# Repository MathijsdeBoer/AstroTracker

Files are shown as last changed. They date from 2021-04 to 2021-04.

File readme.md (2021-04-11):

# Astrotracker

This repository contains the project files for the Astrotracker project.
We're aiming to design a reasonably simple device that allows users to take good shots of the stars at night, without any motion blurring.

## License

As this project involves multiple forms of content, we need to define licenses for each of them separately.
Most well known licenses for code do not cover creative content, nor do they cover CAD.
We try to keep the chosen licenses quite open, to promote sharing and collaborative development.

### Documentation / Development Log

The content in the `doc` directory is licensed under the CC4.0-by-sa-nc license.
This directory is mostly used as a general overview of the concepts explored during the development of the project, and the solutions we find for the inevitable problems along the way.
We'd like to keep that information freely accessible with the chosen license.
Any images that are credited with someone elses name should not be considered to be under this license unless explicitly stated.

### CAD

Any CAD files are licensed under the CERN OHL-W v2.0 or later license.
The way we understand it, this means that if you decided to use (parts of) the designs in your own project, these elements have to be shared with the same license.
For example: we design a doohickey that fenagles the whotsit.
If you incorporate our doohickey design, but don't include our whotsit, you only have to make the design files for the doohickey available.
If you also make changes to the doohickey design files, you must give information about what you changed, and when you changed it, and make them available under the same CERN OHL-W v2.0 or later license.
The recommended approach to sharing the changes is to include these in a `changes.txt` file.
Note that this license only applies to the design _files_, and not a physical object based on them.
The physical object it yours to use, sell, paint, throw in the ocean (please don't), and anything else you can think of.

### Code

Firmware, or other code is licensed under the MIT license.
While this license does not force you to share your changes, we'd like to see your improvements!

Should any part of the text above conflict with any part of the licenses described, the license itself should be considered the correct interpretation.

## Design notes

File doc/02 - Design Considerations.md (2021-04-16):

# Design considerations

The design of the star tracker needs to fulfill a number of prerequesites.
Mainly, it needs to be portable, accurate and in our case, reasonably simple to build.
As we expect that the main manufacturing method of our users is the use of 3D printers, we need to make sure that our designs do not incorporate too many fine details, or too much non-standard hardware if we need to incorporate nuts and bolt, for example.

Additionally, electronic components ought to be easily attainable.
While we'd like to design our own PCBs for our needs, it's probably more likely that Aruino or Raspberry Pi based systems are preferred due to their ubiquity, good support and widely available documentation.
Fancy solutions are nice, but simple solutions are better.
Nevertheless, if we can properly define our PCB specifications and requiremetns we can also design multiple implementations of the board based around a variety of microcontrollers.

## Existing products

If we consider existing star trackers, they share several similarities:

- They can be powered with batteries and with an external power source
- They are mountable on a tripod
- They allow the user to select several speeds
- Mounted cameras are easily aimed at the desired target
- Polar allignment methods are built into the device, or are easily attached
- Some have a go-to function at the cost of size

Taking these features into account, we'd like to distill them down into a so-called Minimum Viable Product (MVP).
This is generally regarded as the minimum amount of working features required to release.
For a star tracker, this is somewhat simple.
We want to turn a mounted camera such that it counteracts the rotation of the earth.
If we can achieve that, we can call it ready for release.

As this is an open source project, "release", of course, means "functional"

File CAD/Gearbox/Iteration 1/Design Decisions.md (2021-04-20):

# 10k : 1 Planetary Gearbox

## Iteration 1

## Design Decisions

This is an initial design for the gearbox that should bring down our stepper motor's rotation to our targeted 10k : 1 reduction.
It was designed with 3D printing in mind, and as such already has some tolerances built in.
The reduction stages are selected as defined in our writeup:

    4 * 4 * 5 * 5 * 5 * 5 = 10,000

Where the `: 1` is left out for clarity.

A module of 2.0 mm for the gears was chosen as a good compromise between size and gear strength.
As we should expect users to attach some expensive equipment to the end, we should probably err on the side of caution, lest the $5000 camera drops on the floor after the teeth shear off.

The current implementation does not, however, use the helical or herringbone (double helical) cut.
Firstly, the used tool to generate the gears has a bug where the module changes as the helical angle increases, which made designing for size more difficult.
Secondly, as the application is not a high-RPM one, the helical cut may not be required after all.

Gear thickness was left at the default 10mm.
Some room for optimization may be found here, though care should be taken to not remove too much as to not reduce gear strength too much.

In terms of planetary gear setups, we've opted to fit as many as physically would fit per stage.
This works out to 5 planetary gears for the 4 : 1 stages, and 4 for the 5 : 1 stages.
This could be reduced to 3
However, we've again erred on the side of caution and opted to distribute any forces through as many gears as we could fit.

The carriers and planetary gears were designed to be fitted with 608 sized ball bearings.
This size of bearing is relatively ubiquitous and should be comparatively cheap.
These should keep things moving quite smoothly, though no tests on designs without bearings have been performed.
Removal of these bearings in favour of a simpler rod and hole setup might also allow us to reduce the thickness of the carriers, reducing overal size.

Finally, we added a little galaxy design to the gears, because it looks neat while reducing a little bit of material.

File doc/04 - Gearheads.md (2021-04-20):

# Gearheads

As we discussed, existing hobby grade motors probably won't be able to rotate at the desired 0.000696 RPM.
We'll need to design a gearbox that can take a higher RPM from the motor, and bring it down to the lower RPM.
Now, gearboxes are a whole can of worms we're going to open.

## The gear

_The Gear._
This little invention that you can [track back thousands of years](https://en.wikipedia.org/wiki/Gear#History) and is still in use today.
From gearboxes in cars to mechanical clocks to cameras and more!
The idea of a gear is that it interlocks with a similar object, and through it's rotation imparts a movement.
Gear ratios, the ratio of the amount of teeth between two or more gears, have the added benefit that they can increase or decrease the amount of torque, at the benefit or cost of rotational speed respectively.

<div style="text-align:center">
Animation of gears
<p>Gears rotating. The smaller gear has a larger rotational velocity to keep up with the larger gear, Simiprof, 2013.</p>
</div>

Now, these things have been around for so long, that humans have tried a lot of things with them, and their design.
Equally ubiquitous are terms for describing very specific parts of the gear.
We won't be going into detail on these.
But we'll have warned you, lest we make a mechanical engineer very sad.

<div style="text-align:center">
Gear terminology
<p>Terminology used to describe the anatomy of a gear, Honaroog, 2007.</p>
</div>

Another value to keep in mind is the [module](https://en.wikipedia.org/wiki/Gear#Standard_pitches_and_the_module_system) of the gear.
This value describes the relationship between the amount of teeth and the pitch diameter (pitch circle on the image).
The lower the module, the smaller the gear and its teeth.

So what about these ratios?
This is pretty simple, really.
If you take the amount of teeth of one gear, and divide it by the amount of teeth on the other gear, you get the gear ratio.
For example: gear A has 10 teeth, and we interface it with gear B with 100 teeth.
In order for gear A to completely rotate gear B, it needs to rotate 10 times to "visit" the 100 teeth of gear B.
Ergo, the gear ratio here is 10 : 1.
10 rotations cause 1 rotation.
The reverse is also true, if we take gear B as our input gear now, every rotation of gear B causes 10 rotations of gear A.
This gear ratio is 1 : 10.
Some people like to use decimal numbers to indicate their ratios, such as 0.1 : 1.
Mainly for less evenly dividable values, such as 23 : 31 to 1 : 1.347.
This is purely a matter of preference, but the end results are the same.

### I like the cut of your ~~jib~~ Gear

Gears can come in a few shapes and sizes, as we've discussed, but they can also come in different cuts.
A cut determines how the teeth are shaped around the axis of rotation.
The most well know cuts are the [straight cuts](https://en.wikipedia.org/wiki/Gear#Spur) (also known as spur gear).
These are what you would picture if you think "gear".
The other popular cut would be the [helical gear](https://en.wikipedia.org/wiki/Gear#Helical).
These have their gears twist around the rotational axis in a, well, helix.
A variation on the helical gear is the double helical, these will switch the direction of their twist halfway along the gear's width.

The main benefit of a straight cut is the larger contact area between two gears.
This allows for a larger change in force application.
Unfortunately, they tend to be somewhat noisy at high speeds.
Their efficiency and simple construction makes them preferable in racing gear boxes, for example.

Helical gears are smoother than the straight cut gears, because they grow and shrink their contact surface gradually as the teeth interact.
You'll find these a lot in you car's gearbox, or other applications where high RPM and low noise are desired.
Downside of them is that they impart a force along the rotational axis, reducing the efficiency, and requiring some measures to counter this thrust.

The double helical gear aims to negate the axial load by doubling up on the helical direction, one half goes one way, the other one goes the other.
These have the benefit of the smooth contact patch provided by the helical gear while generating a net zero lateral force.
This makes them interchangeable with straight cut gears, but substantially more complex to manufacture.

<div style="text-align:center">
Gear Cuts
<p>Differently cut gears. Green is the straight cut, purple is the helical cut and orange is the double helical cut, BavariaSHAPE, 2020</p>
</div>

As we're not dealing with a high RPM application, the exact type of gear should not matter too much.
Helical gears are nice, though, for their increased smoothness.
Double helical gears do the same, but they also look cool.
And why build anything functional while not making it look cool?

There are many, many more gear configurations, but they are not as immediately relevant to our project.

## Metal boxes

Taking a few of these gears, and putting them in a neat little box, is commonly referred to as a gearbox.
Shocker, we know.
But these little (or large) things have been very useful to us.
Gearboxes are used to combine gear ratios into a more useful ratio without having to create very large or very small gears by doing the reductions or increases in several steps.

### Spur gearbox

Spur gearboxes are the simplest combination of gears.
The input gear drives the next, which drives the next, and so on untill you reach the output gear.
Now, the name of this one may imply only straight cut gears are used, but that is not nessecarily true.
It's mainly just the name we could find for it in our internet searches, and we all know that if it's online, it must be true.

They are by far the simplest to design, build and maintain and are as such widely used.
Unfortunately, they also wear a little faster than the planetary gearset, which we'll expand on later.
This is mainly due to the fact that each gear puts full load on the next, which causes stress on the parts and reduces their lifespan.

### Planetary gearset

While stargears are, to the best of our knowledge, not a real thing, sun gears and planetary gears are.
These are found in, get this, planetary gearboxes.
I wonder where they got this term from?
I guess we'll never know.

<div style="text-align:center">
Planetary Gearset
<p>A planetary gearset. Red is the ring gear, blue are the planetary gears, yellow is the sun gear and green is the carrier, Wapcaplet, 2006</p>
</div>

The planetary gearset has a few configurations.
Generally an input and output is defined, and the remaining element is held stationary.
The carrier and planetary gears should be considered part of the same element.
For example: you can take the sun gear as input, and the carrier as output, this would mean that you would need to hold the ring gear stationary
If you want to use the ring gear as output instead, you would have to keep the carrier stationary.

This versatility allows the planetary gearset to be used in various ways at the cost of complexity.
With the spur gearbox, a 10 : 1 reduction requires only 2 gears.
The planetary gearset requires at _least_ 4, preferably 5.
One sun gear, 2 or 3 planetary gears and a ring gear, not to mention the carrier.
If you have to chain several of these reductions, the amount of moving parts increases by a lot.
Additionally, the gears need to be fairly precise, if one planetary gear is slightly out of allignment, it will cause premature wear and failures.
At the cost of this complexity, you gain a lot of reliability and achieve a comparatively smaller footprint for the same reduction.

<div style="text-align:center">
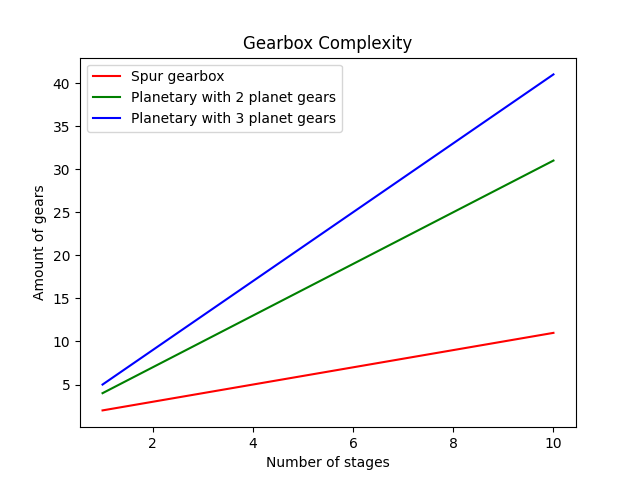
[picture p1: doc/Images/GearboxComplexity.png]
Gearbox complexity increasing with each stage

<p>The amount of gears per stage of reduction for the described gearbox types.</p>
</div>

### Other options

We would be amiss if we were not to mention the worm gear.
Beloved by engineers and birds alike, this gear uses a screw-shaped gear, the worm gear, and interfaces it with a regular gear, the worm wheel.
Because, generally, a worm gear is one long tooth, you can get a very large reduction in a relatively small package.
For example, if we combine our worm gear with a 100 tooth worm wheel, we get a 100 : 1 reduction.

This is not without issues, though.
The worm gear cannot be back-driven, which means that you can't rotate the output to rotate the input, and the output rotational axis is at an angle from the input, which may make designing a gearbox difficult.
On top of this, the efficiency of a worm gear is not as high as other setups due to the increased friction.

Finally, we have the harmonic drive, which uses a flexible inner gear in a solid outer gear.
The flexing gear has a few less teeth than the outer gear, and is flexed into contact by an internal oval shape.
These have also allowed for impressive gear ratios in small packages.
Unfortunately, these are also quite difficult to get right for hobbyists.

## What does this mean for us?

It's hard to say if using a spur gearbox or a planetary gearset is the best for our purpose.
With our relatively low torque and RPM application, neither's strengths and weaknesses really have an impact.
However, as someone will probably mount their expensive camera to the other end, we'll most likely want the improved reliability of the planetary gearsets.
The increased complexity will have to be a hit we'll take.

As we're targeting a 10,000 : 1 total reduction, we have a few options to divide this up:

    10 : 1
    ^ We're using that number in this section, the  ": 1" is implied

    4 * 4 * 5 * 5 * 5 * 5   = 10,000
    10 * 10 * 10 * 10       = 10,000
    100 * 100               = 10,000

There are more possible combinations, of course, but there is a balance to be struck between the amount of stages and keeping the individual reductions relatively small.
As the reduction grows, so does the amount of teeth involved, increasing the size of the gears.
Conversely, as the individual reductions are smaller, more stages are needed to get to the same result.
As we don't want to create gears that are too small or too large, we need to set a minimum and maximum amount of teeth we are willing to use.
We aim to stay above 10, and below 60, though you might find your manufacturing capabilities allowing for values outside this range.
As we use a 3D printer, we shouldn't use a module of lower than 1.0mm, which is about as small as you would reasonably want to go on an FDM printer with a 0.4mm nozzle.

To determine the numbers of teeth we need for our sun gears, planet gears and ring gear, we use [this online tool](http://www.thecatalystis.com/gears/).
With some careful mathematical operations (read: we guessed and tried random numbers) we aimed to generate the reductions described above, and checked them against our desired amount of teeth.
The smallest we could reasonably get a 10 : 1 reduction used too many teeth in the ring gear, and we could not even get a 100 : 1 reduction in the tool.
4 : 1 and 5 : 1 is very achievable, though, and we even found a solution that uses the same amount of teeth in the ring gear, which would let us use the same ring gear for all of our reductions in one neat package!
The found values ended up being:

    4 : 1 Reduction:
        Sun Gear: 16 teeth
        Planet Gear: 16 teeth
        Ring Gear: 48 teeth
    5 : 1
        Sun Gear: 12 teeth
        Planet Gear: 18 teeth
        Ring Gear: 48 teeth

In theory, we could go even smaller with 24 teeth on the ring gear, however, the sun gear would be 8 teeth for the 4 : 1 reduction, and 6 for the 5 : reduction.
Both these fall outside the range we're willing to use, as larger gears allow for a little more load.

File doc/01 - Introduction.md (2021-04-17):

# Introduction

The Stars!

The stars?

Yes! The stars! And those other stellar objects, too, I guess.

What about them?

Have you never wanted to take a photo of them?

Well sure, but my (phone) camera is not good enough to get nice results I can share on my [insert social media] page.
Even the moon can be tricky!

A-ha!
But it does not have to be that hard, you just need to know how to use your equipment to get the results you want!

But how?

Don't worry, people have been taking stellar pictures with cheap hardware for _years_, if they can get their amazing results, your modern smartphone can do it for sure.

## Stellar photography

Depicting the stars is an art as [old as time](https://en.wikipedia.org/wiki/History_of_astronomy).
It should therefore not be surprising that, not long after it was invented, this was also extended to photography.
While the initial [Daguerrotype](https://en.wikipedia.org/wiki/Daguerreotype) style photographs were only usable for bright objects, it wasn't too long after that new developments in photography allowed for more sensitivity to the dimmer objects.
For reference, the first successful Daguerrotype image of the sun's corona in 1851 took an 84 seconds exposure!

<div style="text-align:center">
Daguerrotype of the sun, Johann Julius Friedrich Berkowski, 1851
<p>Johann Julius Friedrich Berkowski, 1851</p>
</div>

It wasn't untill the widespread availability of [dry plate photography](https://en.wikipedia.org/wiki/Dry_plate) that astrophotography became a more manageable process.
Henry Draper, for example, used a 51 minute exposure in 1880 to be the first person to capture the Orion Nebula.
Where his colleague, Andrew Ainslie Common, built his own telescope in his shed and used several hour-long exposures of the same nebula to show stars that the human eye can not see three years later.
A similar process is still used today, known as "stacking".

<div style="text-align:center">
Orion Nebula, Henry Draper, 1880
<p>Henry Draper, 1880</p>
</div>

<div style="text-align:center">
Orion Nebula, Andrew Ainslie Common, 1883
The telescope used by Andrew Ainslie Common, built into his shed, built in 1876, unknown date
<p>Left: Andrew Ainslie Common, 1883, right: The telescope built by him</p>
</div>

If people that built their own telescopes in their backyards, with the technology of the day that fights against them in almost any conceivable way, can take the types of pictures shown above, we sure as hell can do it with the seas of information that can be found on the internet! Right?

Source(s): Wikipedia

## Collecting light

As you may have picked up on, or already knew, taking photos of things requires one element you don't have a lot of at night: light!
Generally speaking, short of going to a brighter area a camera has three things it can do to increase the amount of light that gets to the sensor; increase the diameter of the lens aperture, take a longer exposure, increase the ISO.
The aperture can only open so far, and is generally not enough to make up for the low light alone.
The ISO, simply said, is the camera multiplying the amount of measured light with some value.
Unfortunately, in systems with a low amount of measured data, noise has a strong effect on the end result.
Finally, if you increase the exposure time, you collect light over a longer amount of time, easy!
But hold on!
Doing this also increases the effect of motion blur, which isn't something you want for nice and crispy shots!

All these settings, and they all have their drawbacks!

## So what do _I_ need?

A camera.

Joking aside, you don't really need a good camera, but it's nice if you do.
Amateur astrophotographers have been using old webcams for about as long as they have been available.
More recently, Raspberry Pis have had some level of use, too.
That is not to say that a phone does not work.
At the other end of the scales you have your DSLR/Mirrorless cameras, and dedicated astrocameras.
These may be out of the price range of many people though.
It's worth mentioning that entry level DSLRs tend to be in the $300 bracket, and are usable for things other than pretty star pictures.

The main issue that most budding astrophotographers face is that they simply don't have a stable enough platform to take their pictures with.
While you can freehand a DSLR to take photos of the moon, getting Andromeda may not be as simple.
A good tripod or other stable mount may be needed.
Because these other objects are so dim, you need to increase the amount of time your camera takes to take a picture.
That, or you find a lens with a insanely large aperture, probably at an equally insane price.

But my pictures are still blurry!

Yes, well, while the camera may be perfectly still, the earth isn't.
You may have missed it, but once every 24 hours or so, we do a full rotation!
This has the effect of the illusion that the sky is moving around us.
Whether we are moving, or the sky is has little bearing on the result: The stars start streaking.

<div style="text-align:center">
Star trails, Akiyoshi's Room
<p>Star trails, Akiyoshi's Room, unknown date</p>
</div>

While this has its artistic merit, it might not be what you want.
There's two main ways to solve this. We can decrease exposure time, reducing the amount of light per photo.
This has the issue that you need to take a lot more photos to gather the same amount of light.
Stacking is used to combine these images after the fact.
Alternatively we find a way to keep the camera pointed at the same point in the sky. Enter: The star tracker!

## Star trackers

Star trackers are neat little devices that counter the rotation of the earth.
Generally attached to a nice and steady tripod, they slowly rotate the camera around to, you guessed it, track the stars' motion.
This way you can get a nice and sharp picture of a moving subject in dark settings.

Commercial products already exist to fulfill this purpose.
Their price varies, but they will generally be in the $400 area, depending on your location.
Why spend that amount of money, when you can spend more on materials, time and failures to build one your own?

## Purpose

This writeup is meant for the reader to use as a reference, explanation or supporting document for our design.
Some of you may have other tools you can use that you might want to incorporate in your production process.
It's not unreasonable that at least a few of you have a lathe, CNC, laser cutter, et cetera.
These tools might provide you with better results than a 3D printer can, but you might have to redesign some part(s).
The writeup would then function as a reference to why we did what we did, for you to interpret and adapt to your own needs.

In this repository, we're exploring the design, and implementation details of a star tracker.
What considerations do we have to make, and how do we go about implementing it?
Answers to these questions will hopefully be answered when we have the time to work on this project.
External contributions are also very welcome, and even encouraged!
As this project touches on many different fields (mechanical, electrical, astronomical, hobbyistical, etc.) there will always be someone who knows more on a particular subject than we do, and we encourage these people to point out and/or correct mistakes we make along the way!

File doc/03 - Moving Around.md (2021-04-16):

# Moving Around

How fast do we need to spin our camera around?
Quite simple, as fast as the earth spins!
But how fast does the earth spin?
About 24 hours.
Is that accurate enough?
Probably not.

## The Rotation of the Earth

As our planet tries to keep the sun at an arm's length (it's got quite the fiery temper), it also twirls around it's rotational axis.
It does this every 86,164.0905 seconds, that is 23 hours, 56 minutes and 4.0905 seconds ([thanks Wikipedia!](https://en.wikipedia.org/wiki/Sidereal_time)).
It's worth mentioning that this is in relation to the stars, where as [solar time](https://en.wikipedia.org/wiki/Solar_time) is what we know as the standard 24 hour day (and even that is somewhat inaccurate as the earth orbits the sun!).
The rotation relative to the stars is known as sidereal time.
This is the time we need to use to calculate our desired RPM.

Let's first convert from seconds to minutes:

    86164.0905 / 60 = 1,436.068175

Now that we have the period, we can convert it to frequency:

    1 / 1,436.068175 = 6.9634577063167631299955519173036e-4 rpm

Eesh, that's a lot of significant figures for a very small value.
How much of these do we actually need?

The mathematically inclined among us are probably already able to estimate the rough numbers, but it's always nice to get confirmation.

Let's do some math.

```python
import matplotlib.pyplot as plt

significant_number = 6.9634577063167631299955519173036e-4
sig_figs = [x for x in range(3, 32)]
error = []

for s in sig_figs:
    rounded = round(significant_number, s)
    # Rounding errors at these scales can cause negative numbers
    err = abs((1.0 - (significant_number / rounded)) * 100.0)
    error.append(err)

plt.scatter(x=sig_figs, y=error)
plt.title("Error vs Significant Figures")
plt.xlabel("Significant Figures")
plt.ylabel("Error (%)")
plt.yscale("log")
plt.ylim(10e-24, 1000.0)
plt.show()
```

<div style="text-align:center">
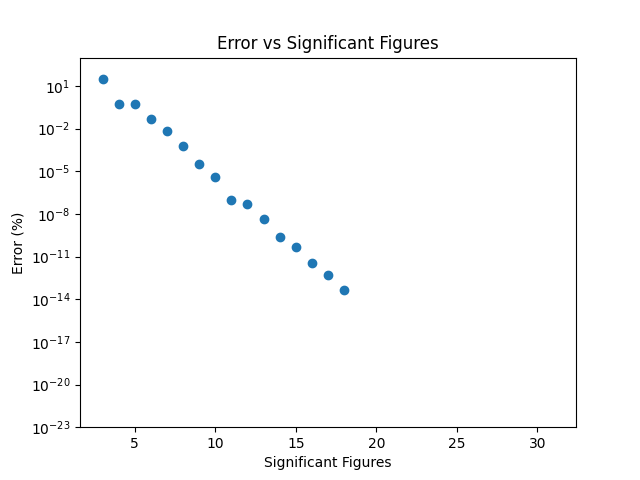
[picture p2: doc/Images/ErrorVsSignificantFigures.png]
Plot of the error vs the amount of significant figures

<p>The error (in %) versus the amount of significant figures, note the plot ending at about 16 figures, this is where Python gave up</p>
</div>

In table form:

| Rounded Value | Error|
| ---: | :--- |
| 0.001 | 30.365422936832363% |
| 0.0007 | 0.5220327669033797% |
| 0.00070 | 0.5220327669033797% |
| 0.000696 | 0.04967968845923654% |
| 0.0006963 | 0.006573406818377592% |
| 0.00069635 | 0.0006073624360780627% |
| 0.000696346 | 3.293884415223047e-05% |
| 0.0006963458 | 4.217491311742094e-06% |
| 0.00069634577 | 9.071303708196865e-08% |
| 0.000696345771 | 5.2893789348473774e-08% |
| 0.0006963457706 | 4.548939003257146e-09% |
| 0.00069634577063 | 2.4071855619922644e-10% |
| 0.000696345770632 | 4.647393581080905e-11% |
| 0.0006963457706317 | 3.397282455352979e-12% |
| 0.00069634577063168 | 5.329070518200751e-13% |
| 0.000696345770631676 | 4.440892098500626e-14% |

Further entries omitted because the values became too small for my Python script to handle.

With this knowledge, we need to set a reasonable error measure.
If we are shooting with an [APS-C](https://en.wikipedia.org/wiki/APS-C) sensor and a 600mm lens, which would probably be the longest lens someone would reasonably want to use (or could afford!).
If we plug this into [Stellarium](https://stellarium.org/en_GB/), a tool that lets you explore the night sky at your location, we arrive at an angular width of a little more than 2 degrees, and an angular height of about 1.5 degrees.
That seems like a respectable goal. Staying under this would mean that you could, in theory track an object over the course of at least a sidereal day without adjusting.

<div style="text-align:center">
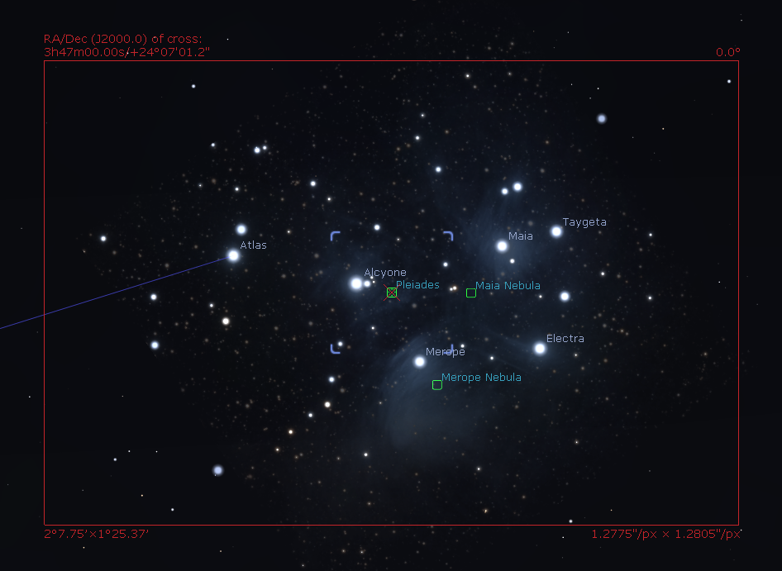
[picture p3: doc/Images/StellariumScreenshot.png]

<p>Screenshot of Stellarium, with the angular dimensions of the image on the bottom left.</p>
</div>

If we can stay under a 1 degree drift per 24 hours, we'll already have a very accurate tracker.
This would work out to about a

`(1 / 360) * 100 = 0.28% error`

Is this attainable?
If we look back at our table, we can see that if we use a value of `6.96e-3` we would already be at an error of 0.05% or

`(x / 360) * 100 = 0.05%`

`x / 360 = 0.0005`

`x = 0.18 degree error`

per 24 hours.

Adding one more significant figure boosts us to a 0.02 degree error, but we should be careful to not fall into the trap of overextending our goals.
Fortunately, changing the amount of significant figures is a firmware detail, and should be relatively easily adapted, depending on our hardware.

## Hardware

Speaking of hardware, we should start looking at what kind of motors we can get.
Mainly, we should select on accuracy.
It would be a shame if we spent all that time calculating our desired output RPM, and it turns out that our motor selection causes it to drift!

### DC motors

The simplest motors you can find are probably the [DC motors](https://en.wikipedia.org/wiki/DC_motor).
They take a free-spinning magnetic core and give it motion by enabling and disabling electromagnets in a certain fashion.
These are often found in RC cars and drones to drive the wheels or propellers.
We'll spare you the exact details how they work, but the gist is, zappy stuff in, spinny stuff out.
The zappier the stuff, the spinnier the out, untill the motor eventually melts.

Now, generally these motors have a certain RPM at a certain voltage.
However, unless you spend a reasonable amount of money on one, the exact RPM is not guaranteed.
As you increase the amount of load (i.e.: More weight) on the motor, the RPM at the same voltage may change.
This is not as large an issue for most applications, and there are ways to accurately control the RPM through some clever circuitry.
However, we feel it's simpler to use a stepper motor instead.

### Stepper motors

[Stepper motors](https://en.wikipedia.org/wiki/Stepper_motor) are also DC motors, with the advantage that it divides a full rotation in equal steps.
Through a certain magnet geometry the output of the shaft can be rotated by a specific amount each time an electromagnet is turned on or off.
Now, the motor does not know _where_ it is pointing, all it knows is where it is going.

<div style="text-align:center">
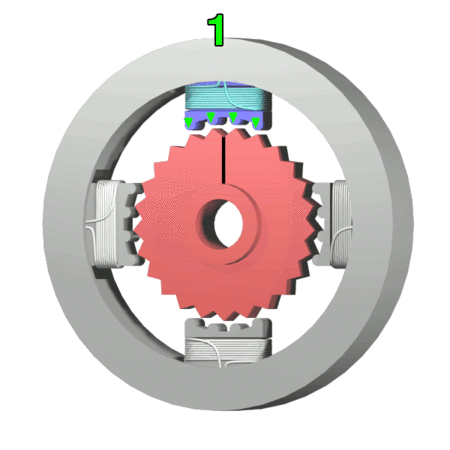
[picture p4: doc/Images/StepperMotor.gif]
Animation showing the function of a Stepper Motor

<p>Animation that shows how a stepper motor works. As each electromagnet is turned on the center magnet moves by a set amount. Wapcaplet/Teravolt, 2010</p>
</div>

This has the advantage that, knowing how many steps each rotation takes, you can be very accurate with your positioning.
The lack of information about your current angle can be mitigated with external solutions, or in some cases, you don't even need to know.
3D Printers make wide use of stepper motors to move their print heads around, to great results.

The downside to stepper motors is that they, well, step.
Ideally we would get a smooth motion to match the stars' movement instead of the slightly jittery movement that is inherent in stepper motors.

### Servo

It would be a miss if we didn't mention [servo motors](https://en.wikipedia.org/wiki/Servomotor).
Servo motors differ from the previous two in that it knows exactly where it is pointing and where it needs to be.
If you tell the motor to point at 90 degrees it will figure out how to get there by taking the difference between it's current position and the target position and using it as an error signal to correct with.
Unfortunately, the drawback is that a servo is only as good as it's position encoder, and cheaper servos don't have very accurate encoders.
Not to say that they are wildly inaccurate for their intended purpose, they just probably won't be accurate enough for our purpose.

### Weapon of choice

All these motors have their own benefits and drawbacks.
Nevertheless, the easiest choice would be the stepper motor.
With the amount of steps being known, we can have a very fine control over the RPM by stepping at a certain rate.
The jitter of the steps should also be reduced if we take a stepper with a sufficiently high amount of steps per revolution.
Additionally, none of the motors (at hobbyist prices) described can reliable rotate at an RPM of 0.000696 rpm.
We'll definately need to use some form of gearbox to reduce the output of the motor, further decreasing the effect of the steps on the photos.

NEMA stepper motors are probably the more well known examples.
These are widely found in various applications because of their standardized design, specified by the [NEMA](https://en.wikipedia.org/wiki/National_Electrical_Manufacturers_Association).
This is not to say that you buy your NEMA stepppers from this association, they just tell manufacturers what the dimensions need to be, where the following number specifies a certain size.
This means that any motor that is sold as a NEMA 8/17/24 by manufacturer A will fit if you initially planned on using the same NEMA motor from manufacturer B without a redesign.
Differences between things such as voltages, holding torques and rated current do exist, so keep that in mind.

<div style="text-align:center">
NEMA 17 motor
<p>NEMA 17 motor, Robotdigg, 2013</p>
</div>

Another well-known little motor is the 28BYJ-48.
This tiny little thing is a staple in a lot of hobby projects due to it's low cost and small size.
Perhaps surprisingly, this motor tends to have more steps per revolution than the average NEMA 17.
It's worth mentioning however, that not all 28BYJ-48 are built to the same specification.
Some have 4096 (!) steps per revolution, some have a few less, some have a lot less.
This is achieved with an internal gearbox that steps down the motor inside, but gear ratios can vary between manufacturers.
When you use one of these, make sure to determine how many steps you have accurately.

<div style="text-align:center">
28BYJ-48 with a stepper driver
<p>28BYJ-48 stepper motor, attached to a ULN2003 stepper driver board, Kushagra Keshari, 2019</p>
</div>

While cheaper NEMA 17 motors are mostly available in 200 steps per revolution (1.8 degree/step), 400 steps per revolution (0.9 degrees/step) motors also exist.
However, these do not stack up against the 4096 steps per revolution (0,0889 degrees/step).
What these motors lack in comparative resolution, they make up in top speed and torque.
We've done some experimenting with the 28BYJ-48, and could not reliably get it to spin faster than about 15 RPM, whereas a NEMA17 will happily do 120RPM with room to spare.
In terms of torque, the holding torque of the 28BYJ-48 is listed as 0.0343 Nm, whereas a NEMA 17 will usually sit between 0.2 Nm and 0.6 Nm.

What do these values mean for our astrotracker, though?

Well, as we will definately need to use our own gearbox to step down the rpm, this will also increase the steps per (output) revolution and output torque of our motors.
Assuming we want to run with a 10,000 : 1 gear ration (10,000 rotations on the input get you 1 full rotation on the output), we would increase our steps per rotation and torque by the same factor 10,000.
This means that an average NEMA 17 would need 2,000,000 steps (0,00018 degrees/step) for a full rotation and would have about 4,000 Nm of torque.
That means it can lift a little over 400kg on the end of a meter long stick (assuming you gearbox does not explode before that!).
The 28BYJ-48 logically needs 40,960,000 steps (0,00000879 degrees / step) and would be able to output 343 Nm of torque, or just under 35 kg at the end of that same stick.

We will be designing for the 28BYJ-48, even with the drawbacks, the high amount of steps per revolution is a definate benefit.
If we were also willing to lose out on a bit of torque, we could even slow the motor down a little and use a less complex gearbox.

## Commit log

2020-09-10 Initial PCB commit
    [Astrotracker_Mainboard.kicad_pcb, Astrotracker_Mainboard.sch]
2020-09-10 Move PCB files to own subdirectory
    [Astrotracker_Mainboard.kicad_pcb, Astrotracker_Mainboard.sch]
2020-09-13 Move files around
    [Astrotracker_Mainboard.kicad_pcb, Astrotracker_Mainboard.sch]
2020-09-18 Arduino Mega based mainboard
    [Astrotracker.kicad_pcb, Astrotracker.sch, Astrotracker_Mainboard.kicad_pcb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]
2021-04-07 Clean out repo for a restart
    [Astrotracker.kicad_pcb, Astrotracker.sch, Astrotracker_Mainboard.kicad_pcb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]
2021-04-13 Add placeholder Electronics project
    [AstroTracker_Mainboard.kicad_pcb, AstroTracker_Mainboard.kicad_sch]
2021-04-13 Add entry on motors
2021-04-13 Also include the Pico Library's images for Readme
2021-04-16 WIP version of gears related writeup
2021-04-17 Gears post updated
2021-04-18 More explanation on our gearbox
2021-04-20 First basic gearbox design
